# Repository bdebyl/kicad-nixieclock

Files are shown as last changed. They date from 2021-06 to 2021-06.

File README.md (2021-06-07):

# KiCAD STM32F0 Nixie Tube Clock

This repository contains the design files and assembly files for my nixie tube
clock design. The code (firmware) can be located at
<https://github.com/bdebyl/stm32-nixieclock>

The assembly files and docs are kept up to date to the best of my abilities.

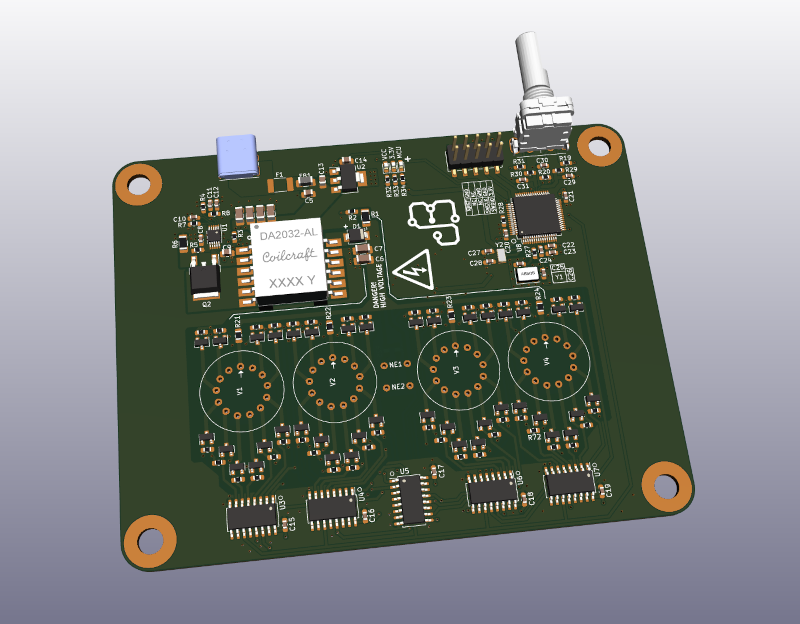
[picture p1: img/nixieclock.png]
Nixie tube clock


## Requirements

To use these design files you will require KiCAD >= 5.99.0, or simply build and
install the latest KiCAD from their git repository.

Additionally, you will need my library files for proper viewing, and
modification of the symbols, footprints, and viewing of 3D models:

Import these as either project or global libraries when opening the KiCAD
project.

- [kicad-footprints](https://github.com/bdebyl/kicad-footprints/tree/bdebyl) @ `24aded49`
- [kicad-symbols](https://github.com/bdebyl/kicad-symbols/tree/bdebyl) @ `2f7d2fdd`
- [kicad-packages3D](https://github.com/bdebyl/kicad-packages3D/tree/bdebyl) @ `60a787a1`

## Additional Hardware

A custom model for an IN-14 holder or stand-off for 3D printing designed by
myself is alos available via Thangs. This was designed to create additional
height for the tubes on the PCB and aesthetic purposes (printed in black).

- [IN-14 Nixie Tube Holder or Standoff](https://thangs.com/brdb/IN14-Nixie-Tube-Holder-or-Standoff-18248)

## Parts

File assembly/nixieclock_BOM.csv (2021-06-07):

Exclude from JLC? | Comment | Designator | Footprint | LCSC Part # | Extended Part? | Mouser Part # | DigiKey Part #
YES | Battery_Cell | BT1 | Battery:BatteryHolder_MPD_BK912-1x2032 |  | NO | - | BK-912-ND
NO | 47uF | C1,C2,C3,C4 | Capacitor_SMD:C_1206_3216Metric_Pad1.42x1.75mm_HandSolder | C96123 | NO | - | -
NO | 100nF | C10,C15,C16,C17,C18,C19,C20,C21,C24 | Capacitor_SMD:C_0603_1608Metric_Pad1.05x0.95mm_HandSolder | C14663 | NO | - | -
NO | 100pF | C11 | Capacitor_SMD:C_0603_1608Metric_Pad1.05x0.95mm_HandSolder | C14858 | NO | - | -
NO | 22nF | C12 | Capacitor_SMD:C_0603_1608Metric_Pad1.05x0.95mm_HandSolder | C21122 | NO | - | -
NO | 1uF | C23 | Capacitor_SMD:C_0603_1608Metric_Pad1.05x0.95mm_HandSolder | C15849 | NO | - | -
NO | 10pF | C25,C26 | Capacitor_SMD:C_0603_1608Metric_Pad1.05x0.95mm_HandSolder | C1634 | NO | - | -
NO | 15pF | C27,C28 | Capacitor_SMD:C_0603_1608Metric_Pad1.05x0.95mm_HandSolder | C1644 | NO | - | -
NO | 10uF | C5,C9,C13,C14 | Capacitor_SMD:C_0805_2012Metric_Pad1.15x1.40mm_HandSolder | C15850 | NO | - | -
YES | 220nF | C6,C7 | Capacitor_SMD:C_1206_3216Metric_Pad1.42x1.75mm_HandSolder |  | NO | - | 445-6995-1-ND
NO | 10nF | C8,C22,C29,C30,C31 | Capacitor_SMD:C_0603_1608Metric_Pad1.05x0.95mm_HandSolder | C57112 | NO | - | -
YES | RFN1LAM6STR | D1 | Personal:SOD128 |  | NO | 755-RFN1LAM6STR | -
NO | LTST-C190GKT | D2,D3,D4 | LED_SMD:LED_0603_1608Metric_Pad1.05x0.95mm_HandSolder | C72043 | NO | - | -
YES | 2.2A | F1 | Fuse:Fuse_1812_4532Metric_Pad1.30x3.40mm_HandSolder |  | NO | 650-MINISMDC110F-2 | -
YES | 600 @ 80MHz 2.5A | FB1 | Inductor_SMD:L_1206_3216Metric_Pad1.42x1.75mm_HandSolder |  | NO | 710-742792118 | -
YES | USB4085-GF-A | J1 | Connector_USB:USB_C_Receptacle_GCT_USB4085 |  | NO | - | 2073-USB4085-GF-ACT-ND
YES | Conn_ARM_JTAG_SWD_10 | J2 | Connector_PinHeader_2.54mm:PinHeader_2x05_P2.54mm_Vertical_SMD |  | NO | - | 609-10129383-910001ALFCT-ND
YES | DA-2032-AL | L1 | Personal:DA2032-AL |  | NO | 994-DA2032-ALB | -
YES | NE-2 | NE1,NE2 | Personal:NE-2 |  | NO | - | -
YES | IRLR3110ZTRPBF | Q2 | Package_TO_SOT_SMD:TO-252-2 |  | NO | 755-RD3P08BBDTL |  | Replaced with equivalent
YES | BSR92P | Q3,Q4 | Package_TO_SOT_SMD:SOT-23 |  | NO | - | BSR92PH6327XTSA1CT-ND
YES | BSS131B | Q5,Q6,Q7,Q8 | Package_TO_SOT_SMD:SOT-23 |  | NO | - | BSS131H6327XTSA1CT-ND
NO | BSS131 | Q9,Q10,Q11,Q12,Q13,Q14,Q15,Q16,Q17,Q18,Q19,Q20,Q21,Q22,Q23,Q24,Q25,Q26,Q27,Q28,Q29,Q30,Q31,Q32,Q33,Q34,Q35,Q36,Q37,Q38,Q39,Q40,Q41,Q42,Q43,Q44,Q45,Q46,Q47,Q48 | Package_TO_SOT_SMD:SOT-23 | C151498 | YES | - | -
NO | 1M | R1 | Resistor_SMD:R_1206_3216Metric_Pad1.42x1.75mm_HandSolder | C17927 | NO | - | -
YES | 160k | R11,R12 | Resistor_SMD:R_0805_2012Metric_Pad1.15x1.40mm_HandSolder | C17485 | YES | - | A126342CT-ND
YES | 100 | R13,R14,R17,R18 | Resistor_SMD:R_0603_1608Metric_Pad1.05x0.95mm_HandSolder |  | NO | - | A106047CT-ND
YES | 63.4k | R2 | Resistor_SMD:R_0603_1608Metric_Pad1.05x0.95mm_HandSolder | C23093 | YES | - | A110281CT-ND
NO | 13k | R21,R22,R23,R24 | Resistor_SMD:R_0805_2012Metric_Pad1.15x1.40mm_HandSolder | C17455 | NO | - | -
YES | 68k | R25,R26 | Resistor_SMD:R_0805_2012Metric_Pad1.15x1.40mm_HandSolder |  | NO | - | A126382CT-ND
NO | 10k | R3,R4,R8,R19,R20,R28,R29,R30,R31 | Resistor_SMD:R_0603_1608Metric_Pad1.05x0.95mm_HandSolder | C25804 | NO | - | -
NO | 3.3k | R32 | Resistor_SMD:R_0603_1608Metric_Pad1.05x0.95mm_HandSolder | C22978 | NO | - | -
NO | 1.2k | R33,R34 | Resistor_SMD:R_0603_1608Metric_Pad1.05x0.95mm_HandSolder | C22765 | NO | - | -
NO | 1M | R35, R36, R37, R38, R39, R40, R41, R42, R43, R44, R45, R46, R47, R48, R49, R50, R51, R52, R53, R54, R55, R56, R57, R58, R59, R60, R61, R62, R63, R64, R65, R66, R67, R68, R69, R70, R71, R72, R73, R74, | Resistor_SMD:R_0603_1608Metric_Pad1.05x0.95mm_HandSolder | C22935 | NO | - | -
YES | 1M | R15, R16 | Resistor_SMD:R_0603_1608Metric_Pad1.05x0.95mm_HandSolder | C22935 | NO | - | -
NO | 22 | R5,R27 | Resistor_SMD:R_0603_1608Metric_Pad1.05x0.95mm_HandSolder | C23345 | NO | - | -
YES | 0.02 | R6 | Resistor_SMD:R_1206_3216Metric_Pad1.42x1.75mm_HandSolder | C127690 | YES | - | A109628CT-ND
YES | 140k | R7 | Resistor_SMD:R_0603_1608Metric_Pad1.05x0.95mm_HandSolder | C22875 | YES | - | A124703CT-ND
YES | 10k | R9,R10 | Resistor_SMD:R_0805_2012Metric_Pad1.15x1.40mm_HandSolder |  | NO | - | A130140CT-ND
YES | EN11-VSM | SW1 | Personal:EN11-VSM1AF20 |  | NO | - | 987-1191-ND
YES | LT3757AEMSE | U1 | Package_SO:MSOP-10-1EP_3x3mm_P0.5mm_EP1.68x1.88mm |  | NO | - | LT3757AEMSE#TRPBFCT-ND
NO | AMS1117-3.3 | U2 | Package_TO_SOT_SMD:SOT-223-3_TabPin2 | C6186 | NO | - | -
NO | 74HC595 | U3,U4,U5,U6,U7 | Package_SO:SOIC-16_4.55x10.3mm_P1.27mm | C5947 | NO | - | -
YES | STM32F051R4Tx | U8 | Package_QFP:LQFP-64_10x10mm_P0.5mm |  | NO | - | -
YES | IN14 | V1,V2,V3,V4 | Personal:IN-14 |  | NO | - | -
NO | 8MHz | Y1 | Crystal:Crystal_SMD_5032-4Pin_5.0x3.2mm | C276420 | YES | - | -
NO | 32.768kHz | Y2 | Crystal:Crystal_SMD_3215-2Pin_3.2x1.5mm | C32346 | NO | - | -
 |  |  | ARM-JTAG-20-10 |  |  | - | 1188-1016-ND

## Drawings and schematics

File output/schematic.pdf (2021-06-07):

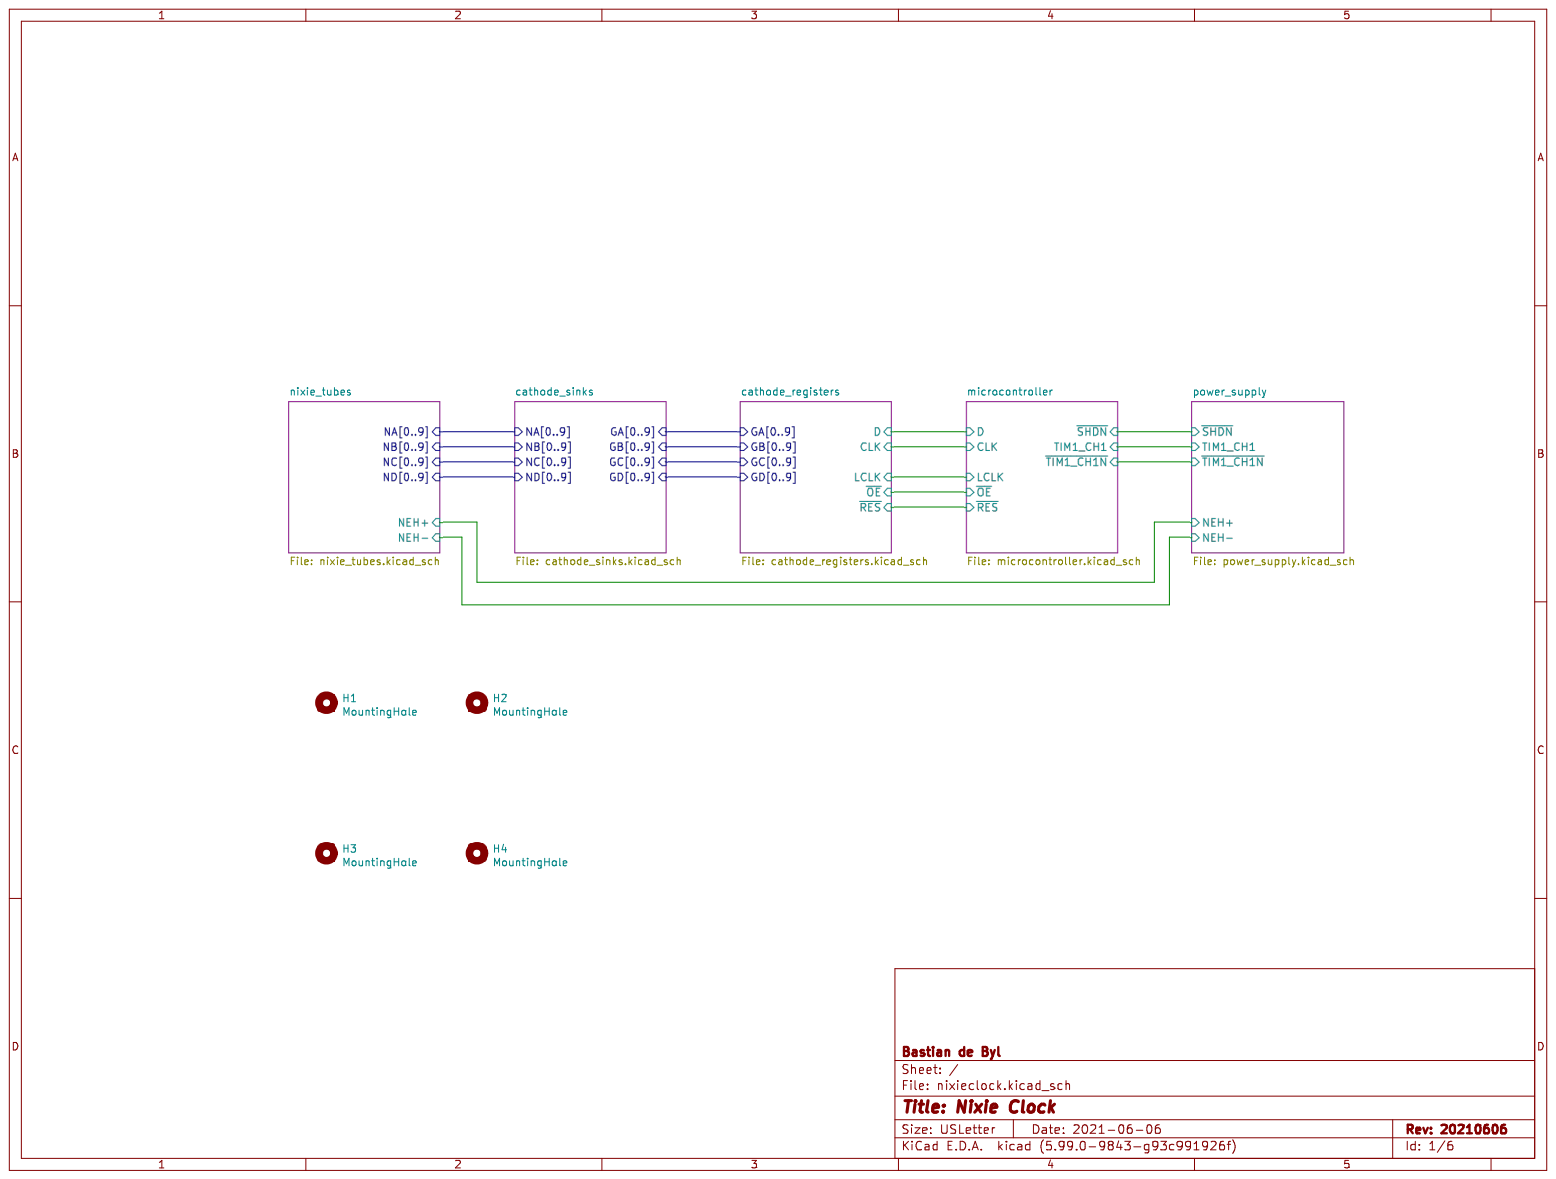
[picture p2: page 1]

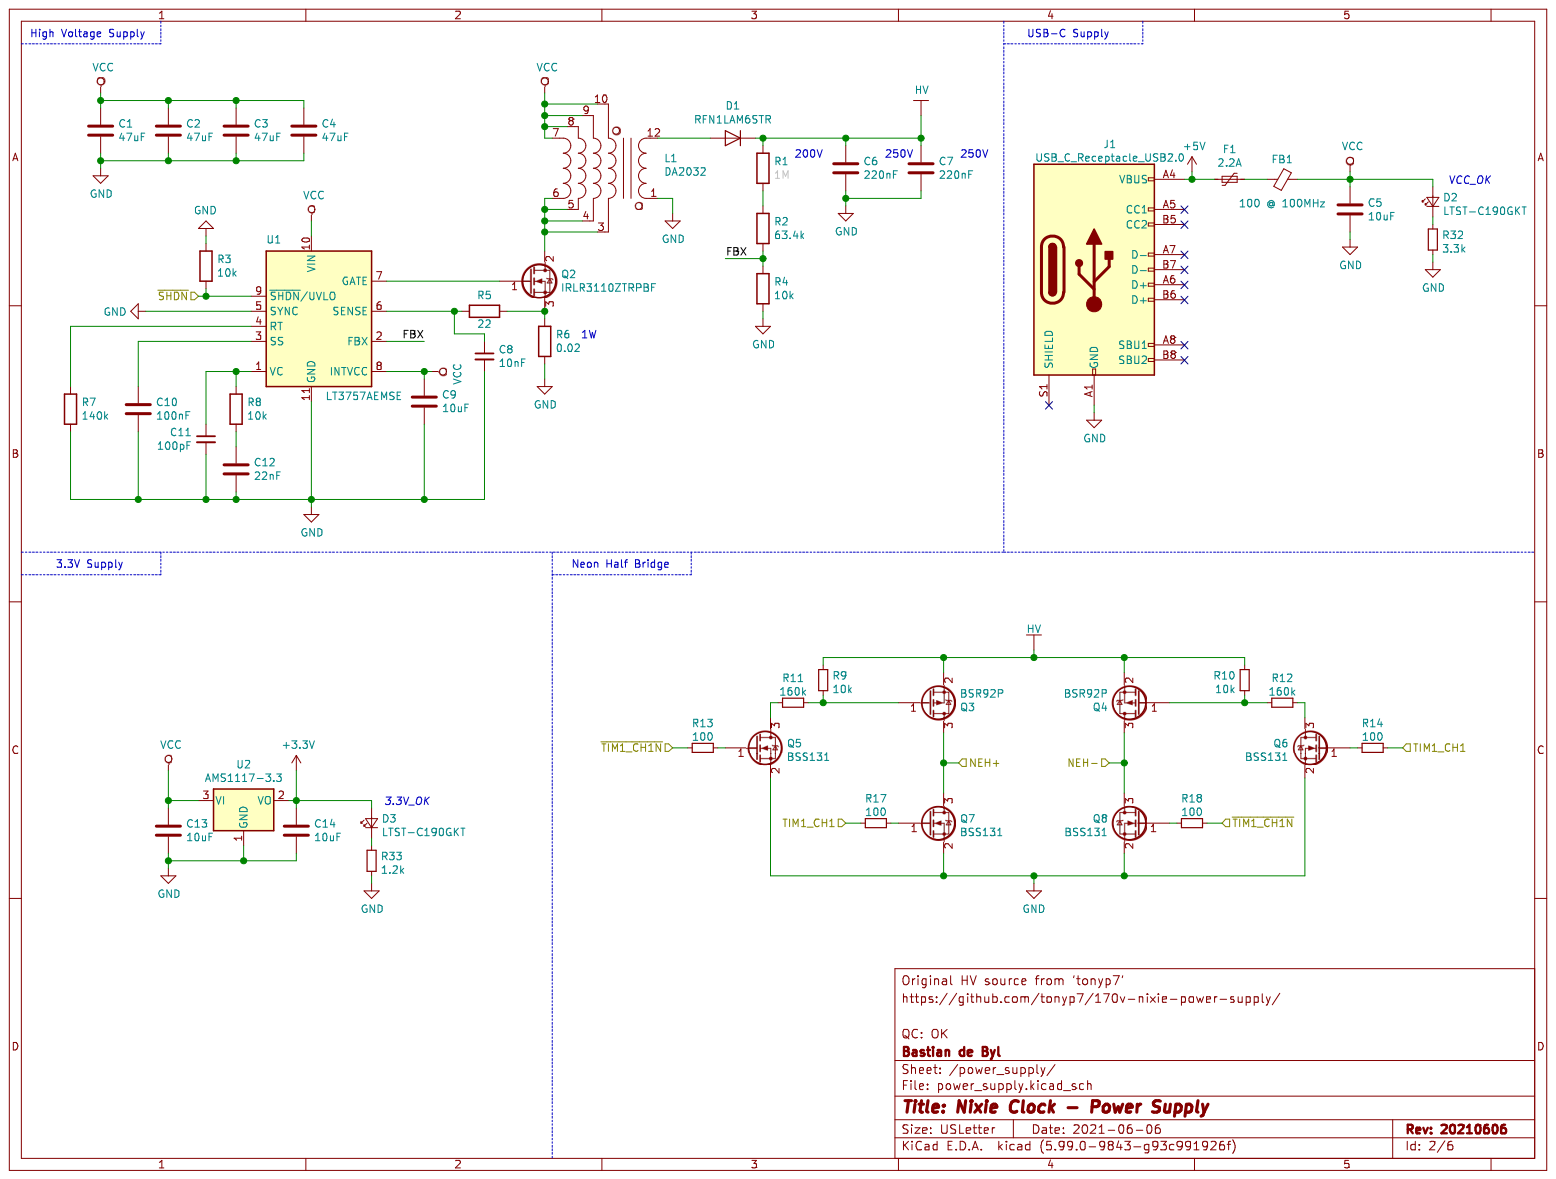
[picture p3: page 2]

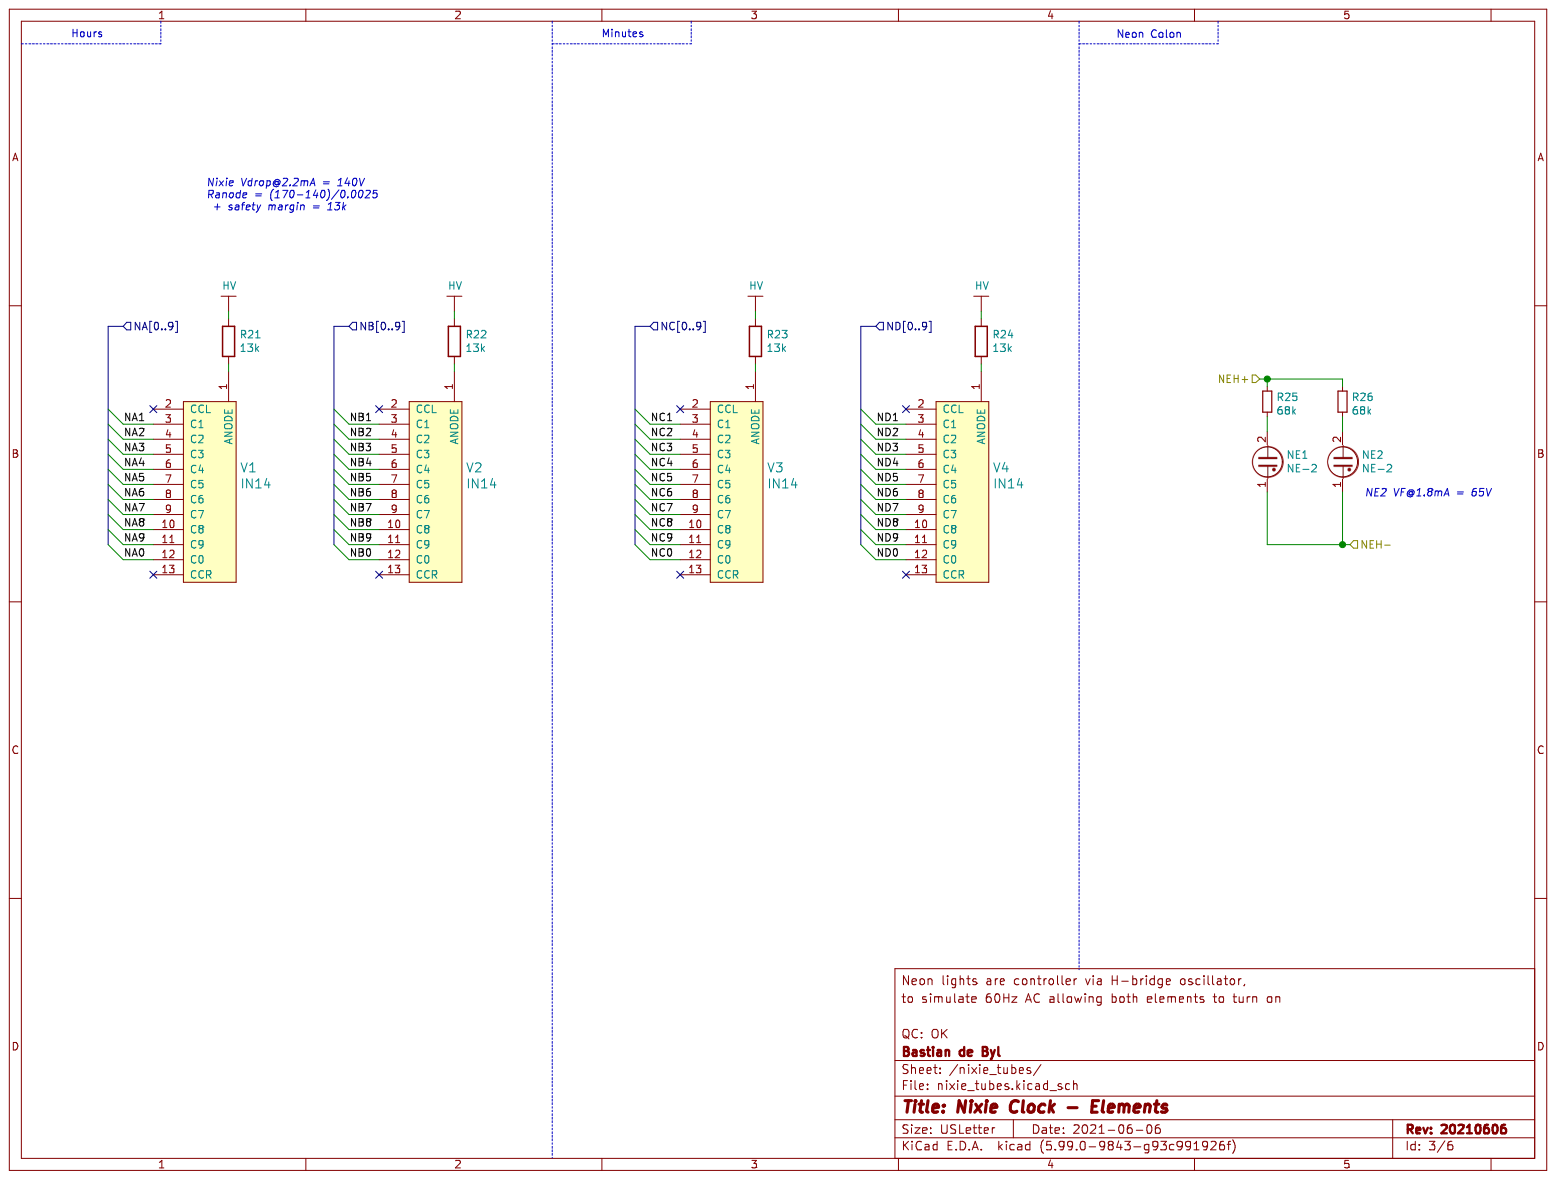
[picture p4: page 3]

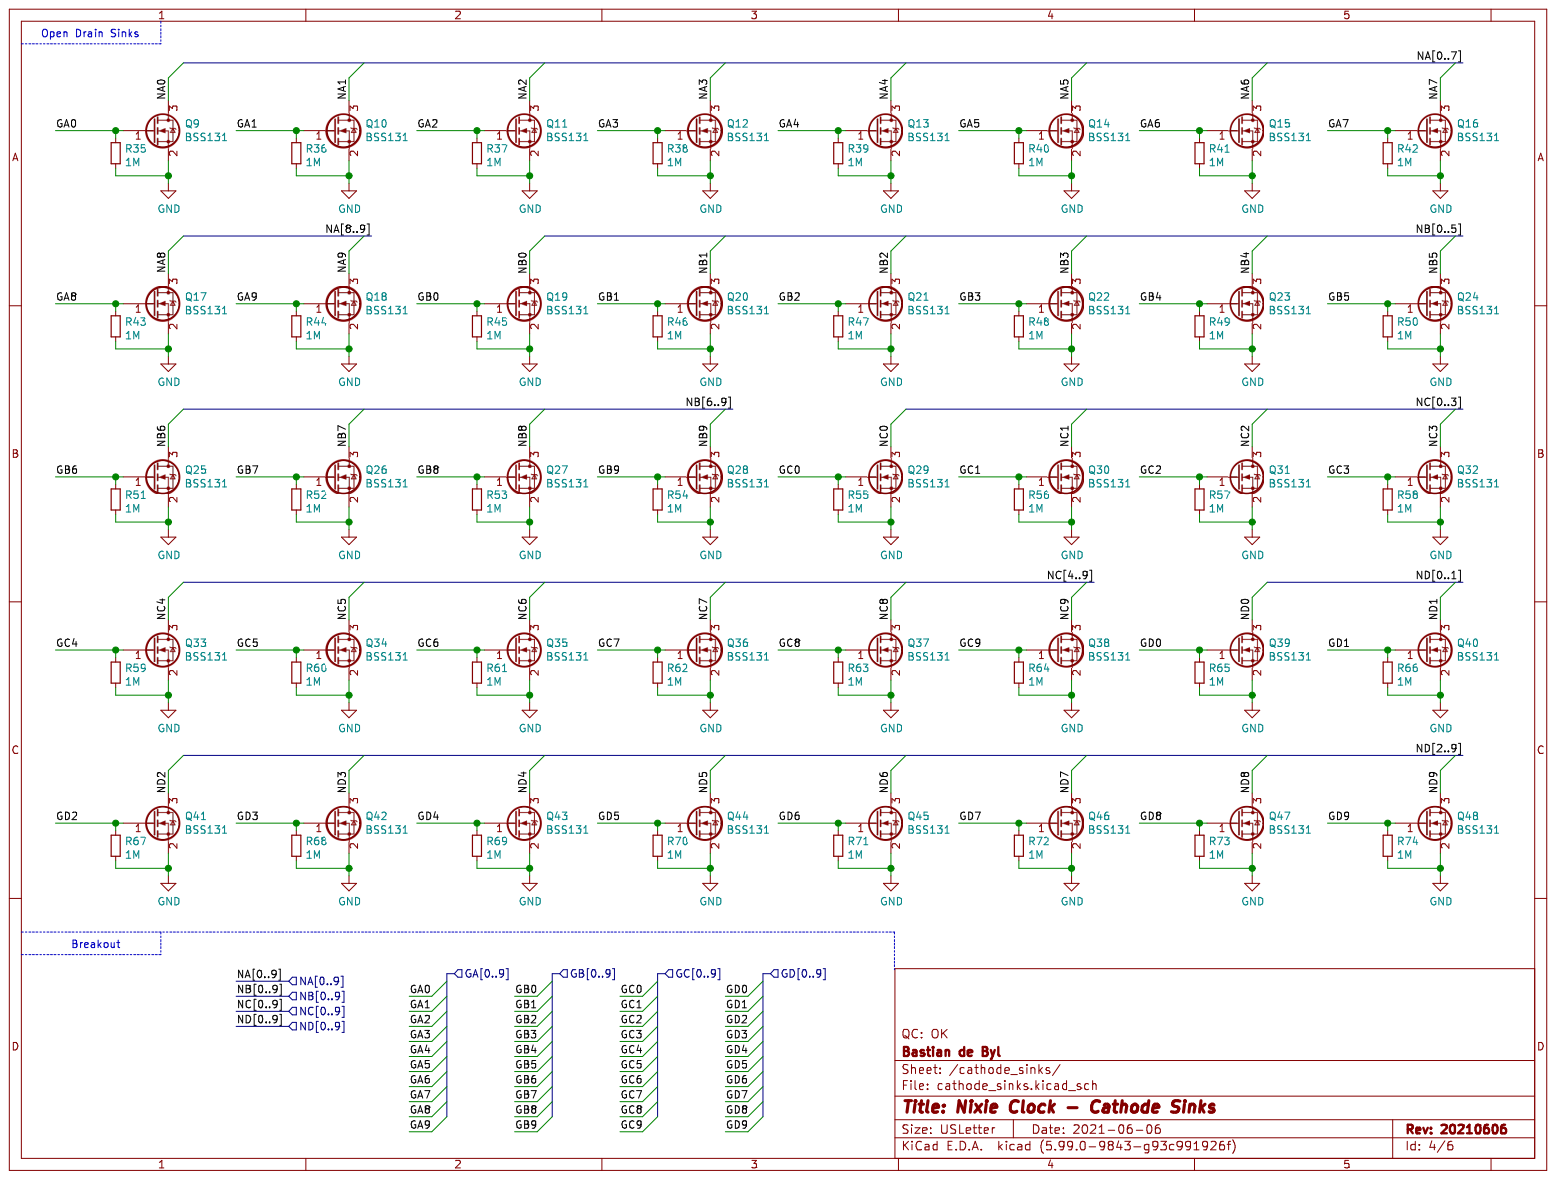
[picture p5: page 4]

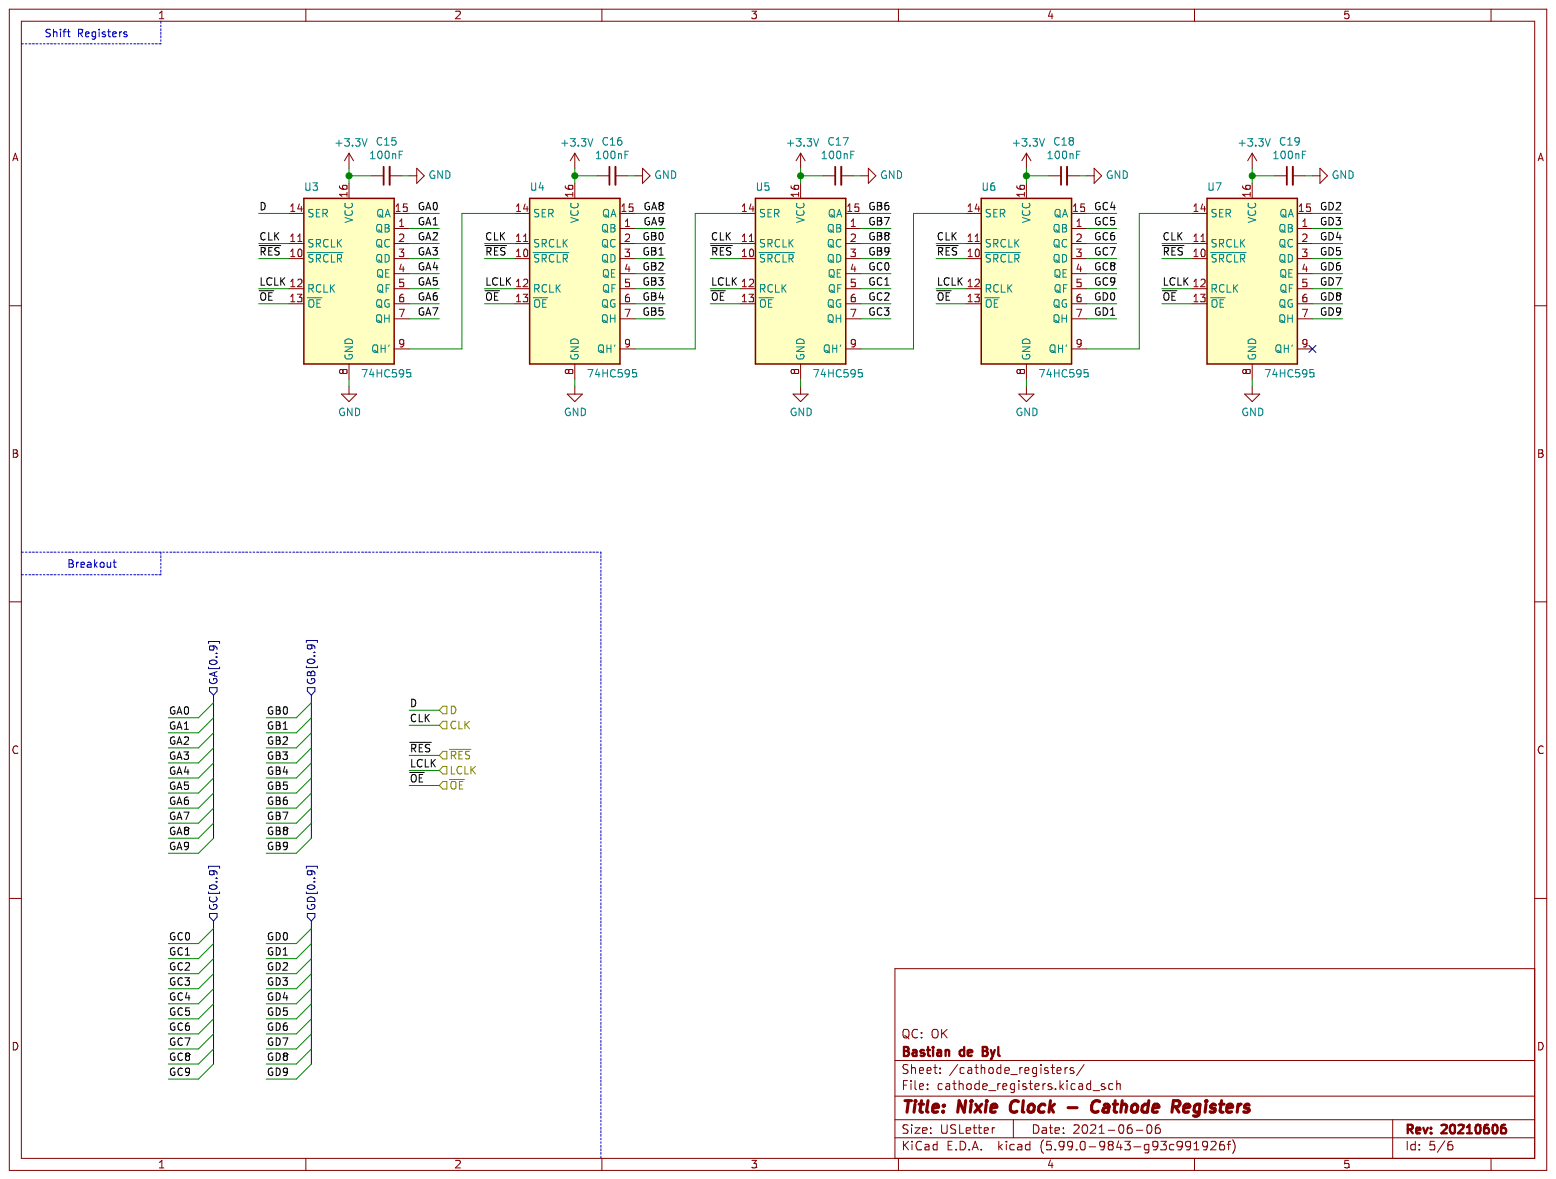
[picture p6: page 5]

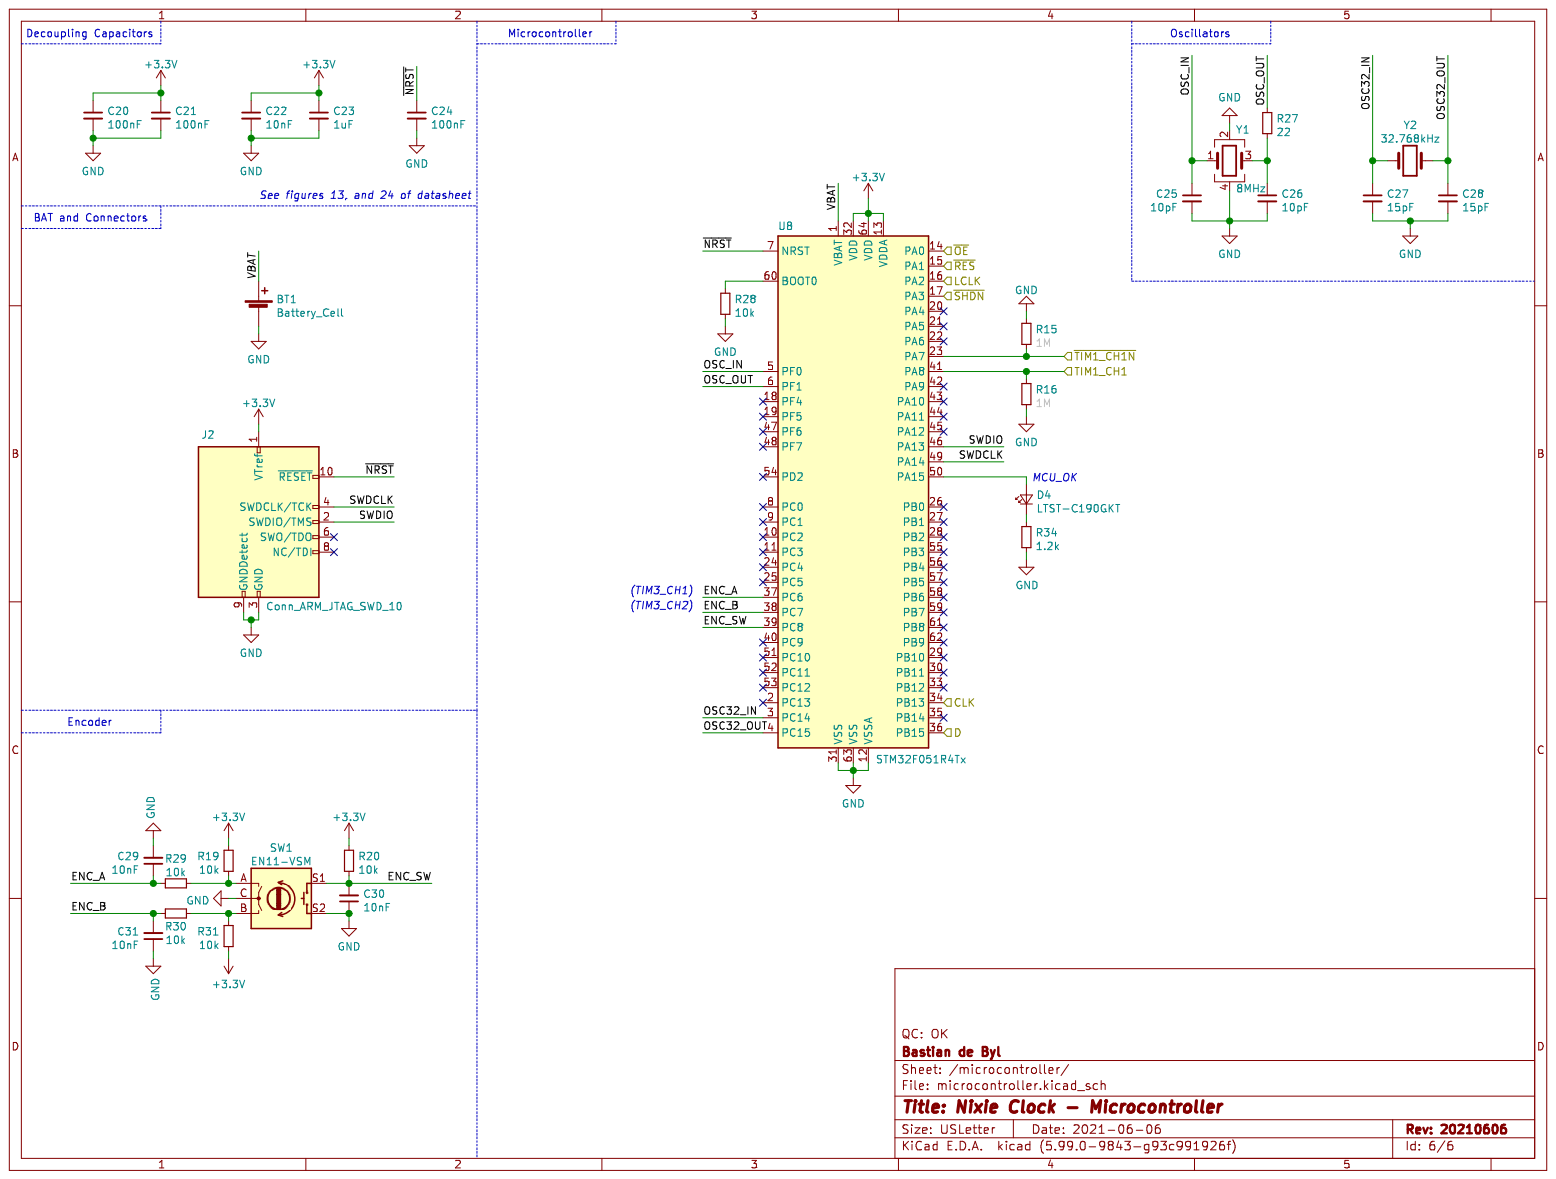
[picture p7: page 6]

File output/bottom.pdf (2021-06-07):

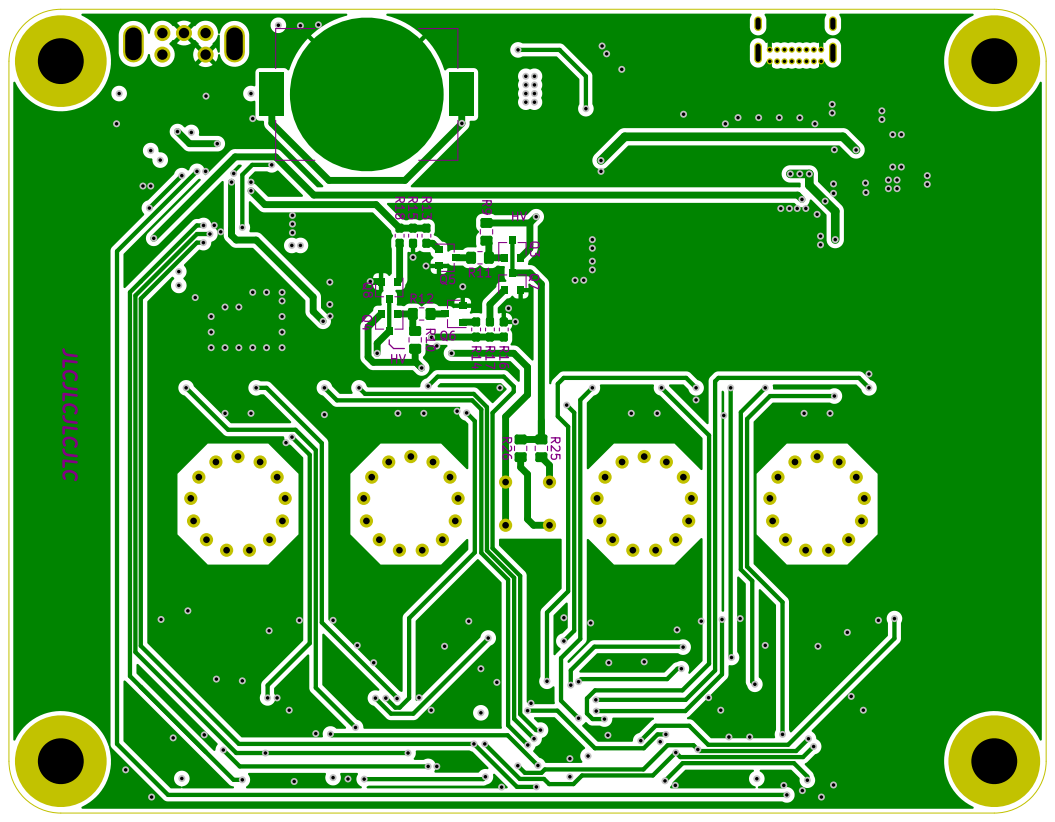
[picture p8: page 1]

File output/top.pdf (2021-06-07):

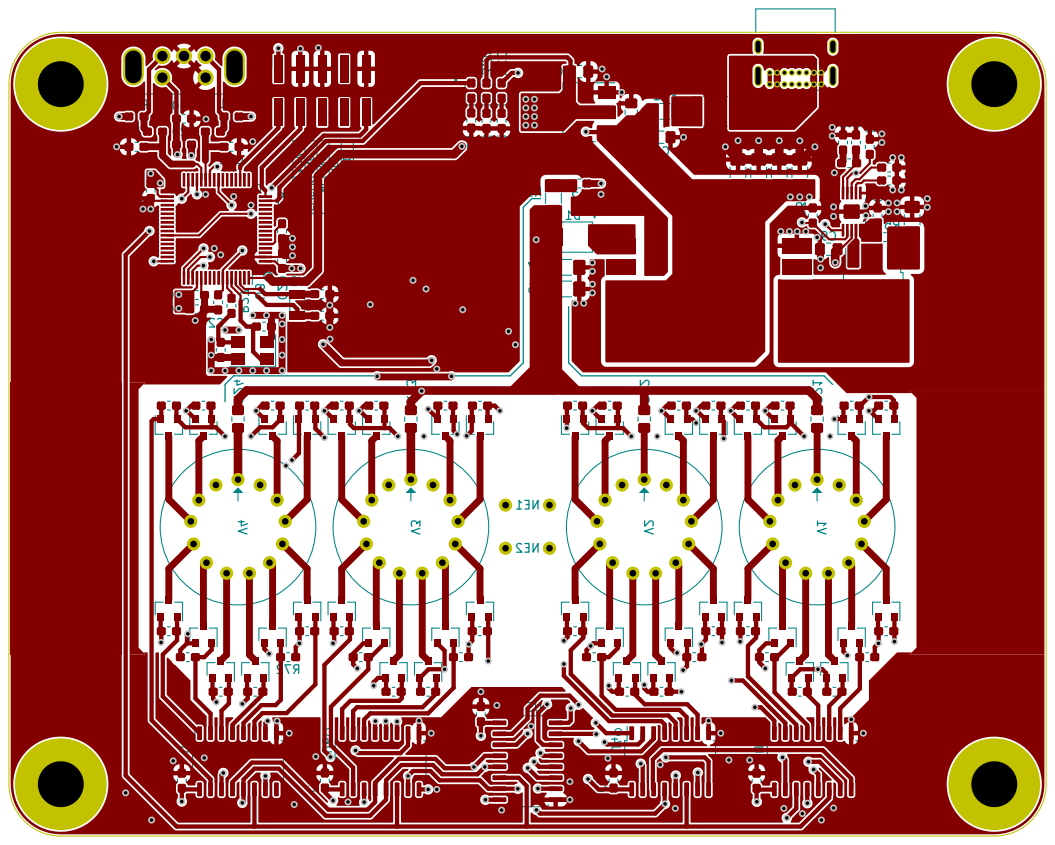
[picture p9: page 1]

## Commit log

2021-03-09 Began working on HV supply, initial commit
    [hv_supply.kicad_sch, nixieclock.kicad_pcb, nixieclock.kicad_sch]
2021-03-10 Finalized HV supply schematic and assigned footprints
    [hv_supply.kicad_sch, nixieclock.kicad_pcb, nixieclock.kicad_sch]
2021-03-11 added nixie breakout, began shift registers
    [cathode_registers.kicad_sch, hv_supply.kicad_sch, nixie_tubes.kicad_sch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]
2021-03-15 finalized power supplies, most footprints, nixie breakout
    [cathode_registers.kicad_sch, hv_supply.kicad_sch, nixie_tubes.kicad_sch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]
2021-03-15 added neon bulbs, finalized cathode registers
    [cathode_registers.kicad_sch, nixie_tubes.kicad_sch, nixieclock.kicad_pcb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]
2021-03-19 began routing PCB, finalized registers design
    [cathode_registers.kicad_sch, cathode_sinks.kicad_sch, nixie_tubes.kicad_sch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]
2021-03-19 began work on microcontroller (stm32f0)
    [microcontroller.kicad_sch, nixieclock.kicad_pcb, nixieclock.kicad_sch]
2021-03-20 mostly finalized pcb layout, silkscreen graphics, etc
    [cathode_registers.kicad_sch, cathode_sinks.kicad_sch, microcontroller.kicad_sch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]
2021-03-22 finalized neon bulb design (todo: pcb jumpers)
    [cathode_registers.kicad_sch, cathode_sinks.kicad_sch, microcontroller.kicad_sch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]
2021-03-23 finalized layout, added encoder
    [microcontroller.kicad_sch, nixie_tubes.kicad_sch, nixieclock.kicad_pcb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]
2021-03-24 finalized design ready for quality check
    [cathode_registers.kicad_sch, cathode_sinks.kicad_sch, microcontroller.kicad_sch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]
2021-03-25 finalized design, fixed USB C receptacle for hand soldering
    [cathode_registers.kicad_sch, microcontroller.kicad_sch, nixie_tubes.kicad_sch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]
2021-03-25 finished project structure, part ordered and finalized
    [cathode_registers.kicad_sch, cathode_sinks.kicad_sch, microcontroller.kicad_sch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]
2021-03-25 added outputs for schematic and gerber view
    [cathode_registers.kicad_sch, cathode_sinks.kicad_sch, microcontroller.kicad_sch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]
2021-06-07 finalized design; fixed NE-2 bulb work
    [cathode_registers.kicad_sch, cathode_sinks.kicad_sch, microcontroller.kicad_sch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]
2021-06-07 Finalized repository for public view
    [nixieclock-B_Cu.gbr, nixieclock-B_Mask.gbr, nixieclock-B_Paste.gbr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]
2021-06-07 Added link to 3d printable standoff
